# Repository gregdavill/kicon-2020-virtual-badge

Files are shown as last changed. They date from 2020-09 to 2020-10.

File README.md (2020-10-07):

# KiCon 2020 Virtual Badge by Greg Davill

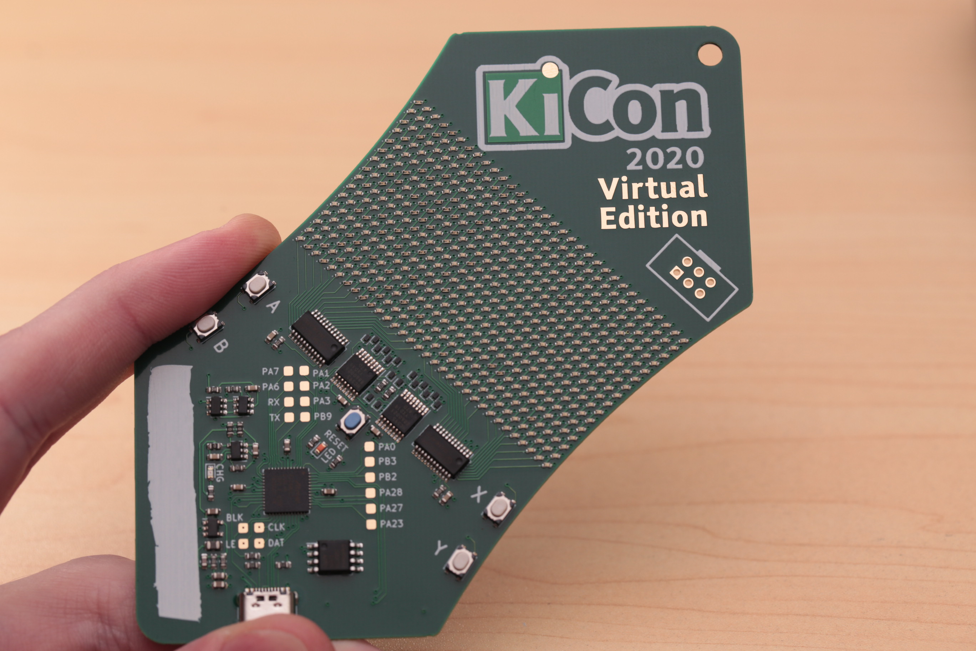
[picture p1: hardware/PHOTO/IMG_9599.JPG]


Based off the design+template by [Thomas Flummer](https://gitlab.com/flummer/kicon-2020-virtual-badge)

I was inspired by the design Thomas made, and wanted to try and extend the badge with more LEDs. I'm using a similar architecture to the LED panels on the d20 and small LED cube I built, except this only has 1 colour of LED in the Matrix.

## Firmware

I've not coded up firmware for a display like this with a microcontroller before, and I've had trouble with the SAMD21's DMA controller and cyclic descriptors in the past. The display will require constant attention from the SAMD as it is a multiplexed display, I'm hoping that implementing a framebuffer + Binary Coded Modulation will be possible.

## Assembly

The LED matrix is 32x16. Or 512 individual LEDs, these are all 0402 in size, so manual assembly may not be for the casual electronics enthusiast.
At any rate I'd recommend using a solderpaste stencil and reflow oven.

## Making your own

If you want to make your own, I have included the gerbers, in case you don't want to install the nightly version.
The board is 4 layers mostly to assist in routing of the matrix. The cost difference between 2L and 4L at JLC is only $5 on their barebones service.

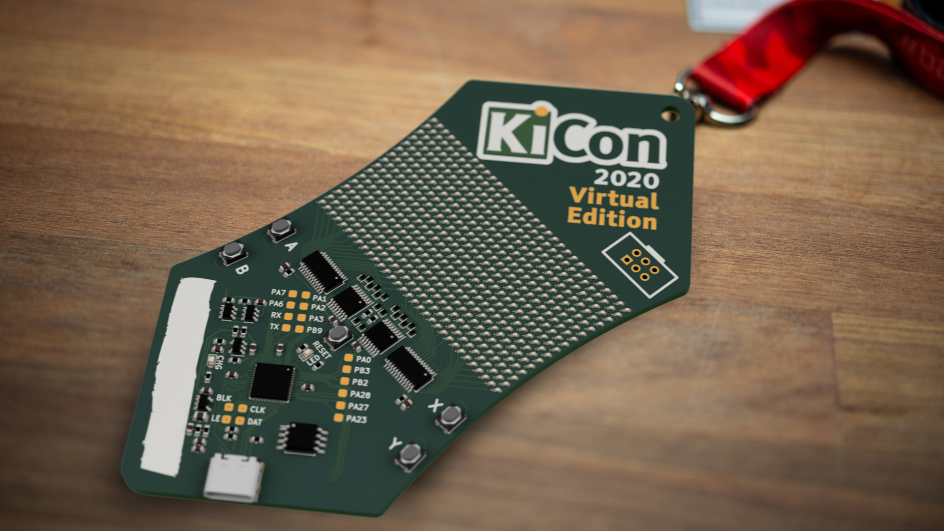
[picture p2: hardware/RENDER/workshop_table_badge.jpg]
Render


## Please share

If you decide to make this badge or a variant of it, please share images so we can all see it and get inspired. If sharing on social media, please use the #badgelife tag and please let [me](https://twitter.com/gregdavill) and [thomas](https://thomasflummer.com/) know, I would love to see what you have made!

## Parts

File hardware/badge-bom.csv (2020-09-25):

Reference | Quantity | Value | Footprint | Datasheet | Mfg | PN | VALUE
C10 | 1 | 10pF | Capacitor_SMD:C_0603_1608Metric | ~ | Samsung Electro-Mechanics | CL10C100JB81PNC
C12 | 1 | 4.7uF | Capacitor_SMD:C_0603_1608Metric | ~ | Samsung Electro-Mechanics | CL10A475KO8NNNC
C5 | 1 | 1uF | Capacitor_SMD:C_0603_1608Metric | ~ | Samsung Electro-Mechanics | CL10B105KO8NNNC
C6 C1 C2 C3 C4 C8 C11 | 7 | 100nF | Capacitor_SMD:C_0603_1608Metric | ~ | Samsung Electro-Mechanics | CL10B104KB8NNNC
C7 C9 C13 C14 | 4 | 10uF | Capacitor_SMD:C_0603_1608Metric | ~ | Samsung Electro-Mechanics | CL10A106MO8NQNC
D1 D2 D3 D4 D5 D6 D7 D8 D9 D10 D11 D12 D13 D14 D15 D16 D17 D18 D19 D20 D21 D22 D23 D24 D25 D26 D27 D28 D29 D30 D31 D32 D33 D34 D35 D36 D37 D38 D39 D40 D41 D42 D43 D44 D45 D46 D47 D48 D49 D50 D51 D52 D53 D54 D55 D56 D57 D58 D59 D60 D61 D62 D63 D64 D65 D66 D67 D68 D69 D70 D71 D72 D73 D74 D75 D76 D77 D78 D79 D80 D81 D82 D83 D84 D85 D86 D87 D88 D89 D90 D91 D92 D93 D94 D95 D96 D97 D98 D99 D100 D101 D102 D103 D104 D105 D106 D107 D108 D109 D110 D111 D112 D113 D114 D115 D116 D117 D118 D119 D120 D121 D122 D123 D124 D125 D126 D127 D128 D129 D130 D131 D132 D133 D134 D135 D136 D137 D138 D139 D140 D141 D142 D143 D144 D145 D146 D147 D148 D149 D150 D151 D152 D153 D154 D155 D156 D157 D158 D159 D160 D161 D162 D163 D164 D165 D166 D167 D168 D169 D170 D171 D172 D173 D174 D175 D176 D177 D178 D179 D180 D181 D182 D183 D184 D185 D186 D187 D188 D189 D190 D191 D192 D193 D194 D195 D196 D197 D198 D199 D200 D201 D202 D203 D204 D205 D206 D207 D208 D209 D210 D211 D212 D213 D214 D215 D216 D217 D218 D219 D220 D221 D222 D223 D224 D225 D226 D227 D228 D229 D230 D231 D232 D233 D234 D235 D236 D237 D238 D239 D240 D241 D242 D243 D244 D245 D246 D247 D248 D249 D250 D251 D252 D253 D254 D255 D256 D257 D258 D259 D260 D261 D262 D263 D264 D265 D266 D267 D268 D269 D270 D271 D272 D273 D274 D275 D276 D277 D278 D279 D280 D281 D282 D283 D284 D285 D286 D287 D288 D289 D290 D291 D292 D293 D294 D295 D296 D297 D298 D299 D300 D301 D302 D303 D304 D305 D306 D307 D308 D309 D310 D311 D312 D313 D314 D315 D316 D317 D318 D319 D320 D321 D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 | 512 | LED | LED_SMD:LED_0402_1005Metric | ~ | Foshan NationStar Optoelectronics | NCD0402O1
D513 | 1 | LED | LED_SMD:LED_0603_1608Metric | ~ | Foshan NationStar Optoelectronics | NCD0603C1
D514 | 1 | CHRG | LED_SMD:LED_0603_1608Metric | ~ | Foshan NationStar Optoelectronics | NCD0603Y1
IC1 | 1 | SAMD21G18A | Package_DFN_QFN:QFN-48-1EP_7x7mm_P0.5mm_EP5.3x5.3mm |  | Microchip Tech | ATSAMD21G16L-MNT | SAMD21G18A-MU
J1 | 1 | USB_C | Connectors:USB_C_Receptacle_U262-161N-4BVC11 | https://www.usb.org/sites/default/files/documents/usb_type-c.zip | XKB Connectivity | U262-161N-4BVC11
J2 | 1 | DEBUG | Connector_PinHeader_2.54mm:PinHeader_1x06_P2.54mm_Vertical | ~
J3 | 1 | LiPo 1S | Connectors:PH2.0-SMD-Horizontal | ~ | JST Sales America | S2B-PH-SM4-TB(LF)(SN)
L1 | 1 | 2.2uH | Inductor_SMD:L_0805_2012Metric | ~ | Sunltech Tech | SLM20122R2MIT
Q1 Q2 Q3 Q4 Q5 Q6 Q7 Q8 Q9 Q10 Q11 Q12 Q13 Q14 Q15 Q16 | 16 | 3412 | Package_TO_SOT_SMD:SOT-883 | ~ | LRC | LP0404N3T5G
R1 R2 R16 | 3 | 2k | Resistor_SMD:R_0603_1608Metric | ~ | UNI-ROYAL(Uniroyal Elec) | 0603WAF2001T5E
R10 | 1 | 100 | Resistor_SMD:R_0603_1608Metric | ~ | UNI-ROYAL(Uniroyal Elec) | 0603WAF1000T5E
R12 R13 R14 | 3 | 1 | Resistor_SMD:R_0603_1608Metric | ~ | UNI-ROYAL(Uniroyal Elec) | 0603WAF0000T5E
R17 | 1 | 360k | Resistor_SMD:R_0603_1608Metric | ~ | UNI-ROYAL(Uniroyal Elec) | 0603WAF3603T5E
R18 | 1 | 82k | Resistor_SMD:R_0603_1608Metric | ~ | UNI-ROYAL(Uniroyal Elec) | 0603WAF8202T5E
R3 R4 | 2 | 5.1k | Resistor_SMD:R_0603_1608Metric | ~ | UNI-ROYAL(Uniroyal Elec) | 0603WAF5101T5E
R5 | 1 | 10k | Resistor_SMD:R_0603_1608Metric | ~ | UNI-ROYAL(Uniroyal Elec) | 0603WAF1002T5E
R6 R11 R15 | 3 | 1k | Resistor_SMD:R_0603_1608Metric | ~ | UNI-ROYAL(Uniroyal Elec) | 0603WAF1001T5E
R7 R8 R9 | 3 | 4.7k | Resistor_SMD:R_0603_1608Metric | ~ | UNI-ROYAL(Uniroyal Elec) | 0603WAF4701T5E
SW1 | 1 | A | Button_Switch_SMD:SW_SPST_PTS810 | ~ | C&K | PTS810SJK250SMTRLFS
SW2 | 1 | B | Button_Switch_SMD:SW_SPST_PTS810 | ~ | C&K | PTS810SJK250SMTRLFS
SW3 | 1 | X | Button_Switch_SMD:SW_SPST_PTS810 | ~ | C&K | PTS810SJK250SMTRLFS
SW4 | 1 | Y | Button_Switch_SMD:SW_SPST_PTS810 | ~ | C&K | PTS810SJK250SMTRLFS
SW5 | 1 | RESET | Button_Switch_SMD:SW_SPST_PTS810 | ~ | C&K | PTS810SJK250SMTRLFS
TP1 | 1 | RX | Connectors:TestPoint_Large | ~
TP10 | 1 | PA28 | Connectors:TestPoint_Large | ~
TP11 | 1 | PA27 | Connectors:TestPoint_Large | ~
TP12 | 1 | PA6 | Connectors:TestPoint_Large | ~
TP13 | 1 | PB23 | Connectors:TestPoint_Large | ~
TP14 | 1 | PA7 | Connectors:TestPoint_Large | ~
TP15 | 1 | PA0 | Connectors:TestPoint_Large | ~
TP16 | 1 | CLK | Connectors:TestPoint_Large | ~
TP17 | 1 | LE | Connectors:TestPoint_Large | ~
TP18 | 1 | BLK | Connectors:TestPoint_Large | ~
TP2 | 1 | TX | Connectors:TestPoint_Large | ~
TP3 | 1 | DAT | Connectors:TestPoint_Large | ~
TP4 | 1 | PB3 | Connectors:TestPoint_Large | ~
TP5 | 1 | PA1 | Connectors:TestPoint_Large | ~
TP6 | 1 | PB2 | Connectors:TestPoint_Large | ~
TP7 | 1 | PA2 | Connectors:TestPoint_Large | ~
TP8 | 1 | PA3 | Connectors:TestPoint_Large | ~
TP9 | 1 | PB9 | Connectors:TestPoint_Large | ~
U1 U2 | 2 | 74HC595 | Package_SO:TSSOP-16_4.4x5mm_P0.65mm | http://www.ti.com/lit/ds/symlink/sn74hc595.pdf | Nexperia | 74HC595PW\,118
U3 U4 | 2 | TLC59025 | Package_SO:SSOP-24_3.9x8.7mm_P0.635mm |  | Texas Instruments | TLC59282DBQR
U5 | 1 | GD25Q32C | Package_SO:SOIC-8_5.23x5.23mm_P1.27mm |  | GigaDevice Semicon Beijing | GD25Q32CSIGR
U6 | 1 | DW01 | Package_TO_SOT_SMD:SOT-23-6 |  | Guangdong Hottech | DW01
U7 | 1 | TLV62569DBV | Package_TO_SOT_SMD:SOT-23-5 | http://www.ti.com/lit/ds/symlink/tlv62569.pdf | Texas Instruments | TLV62569DBVR
U8 | 1 | PM8205A | Package_TO_SOT_SMD:SOT-23-6 |  | PN SILICON | PM8205A
U9 | 1 | HX4054A | Package_TO_SOT_SMD:SOT-23-5 |  | HX(hengjiaxing) | HX4054A
X1 | 1 | #badgelife | badgelife_sao_v169bis:Badgelife-SAOv169-BADGE-2x3

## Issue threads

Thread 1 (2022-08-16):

Pin Allocation for the clock and data lines to the are not optimal

TomKeddie, 2022-08-16:
It's been a while since i worked with this design but I wanted to note here for future reference that white wires are needed to get the sercom/pin allocation correct and use DMA for the led array.

I'll update this issue with the white wires I added but these pin allocations don't allow use of the internal sercom serialiser and thus DMA.

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

gregdavill, 2022-08-17:
Yes, I've actually got a hardware bodge on the one I built to swap these pins to the correct ones.

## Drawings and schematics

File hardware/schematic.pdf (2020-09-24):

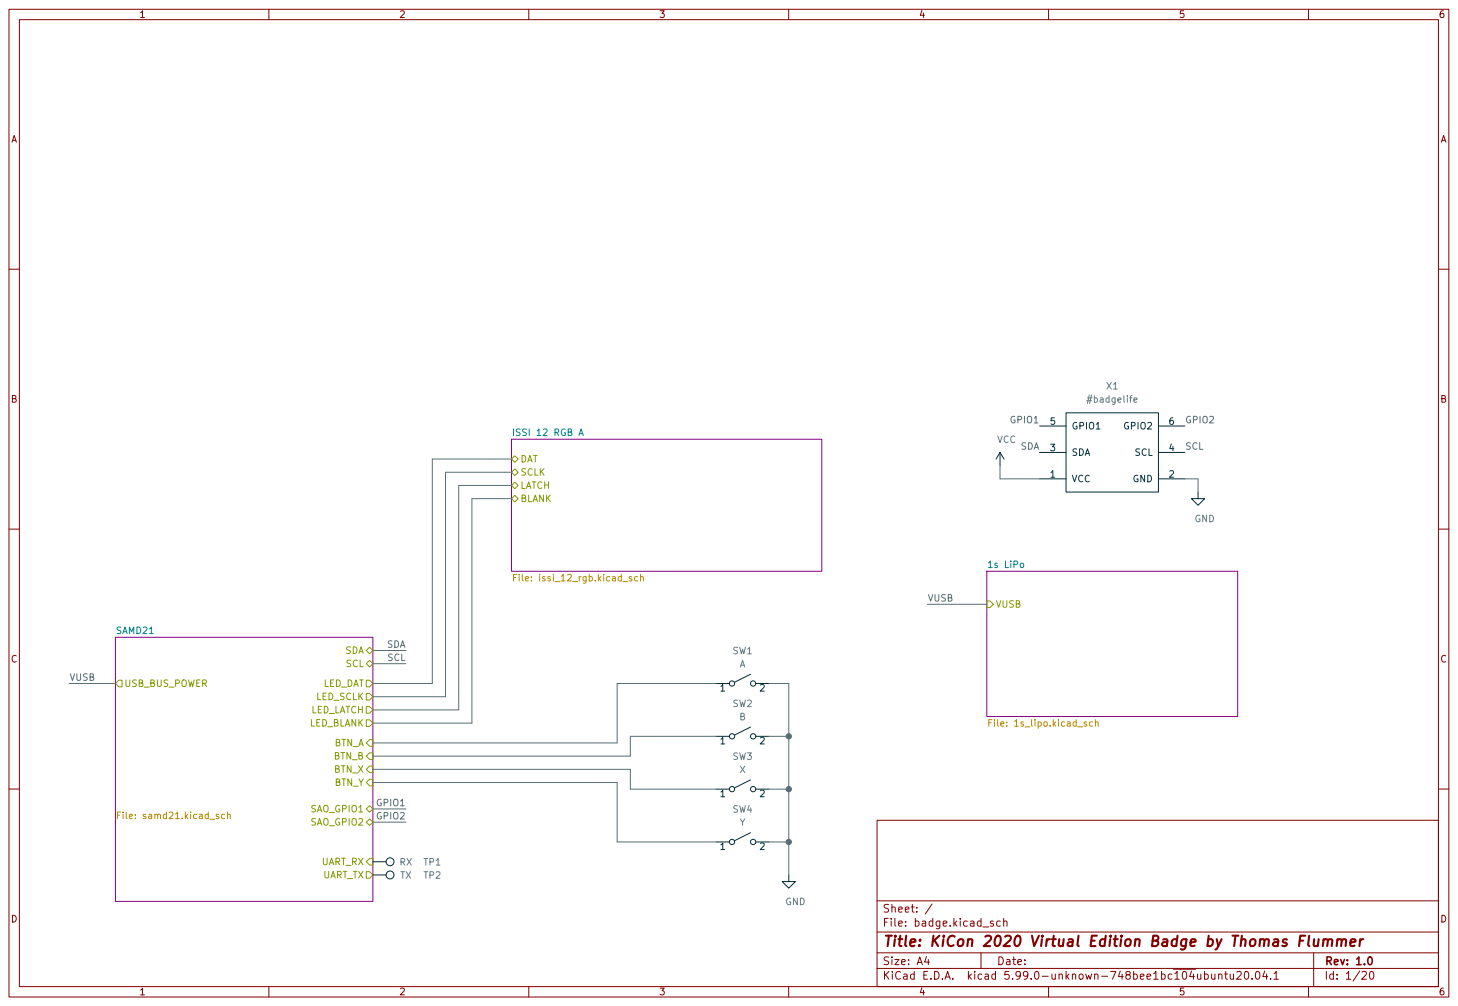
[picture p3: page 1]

Id: 1/20 Title: KiCon 2020 Virtual Edition Badge by Thomas Flummer

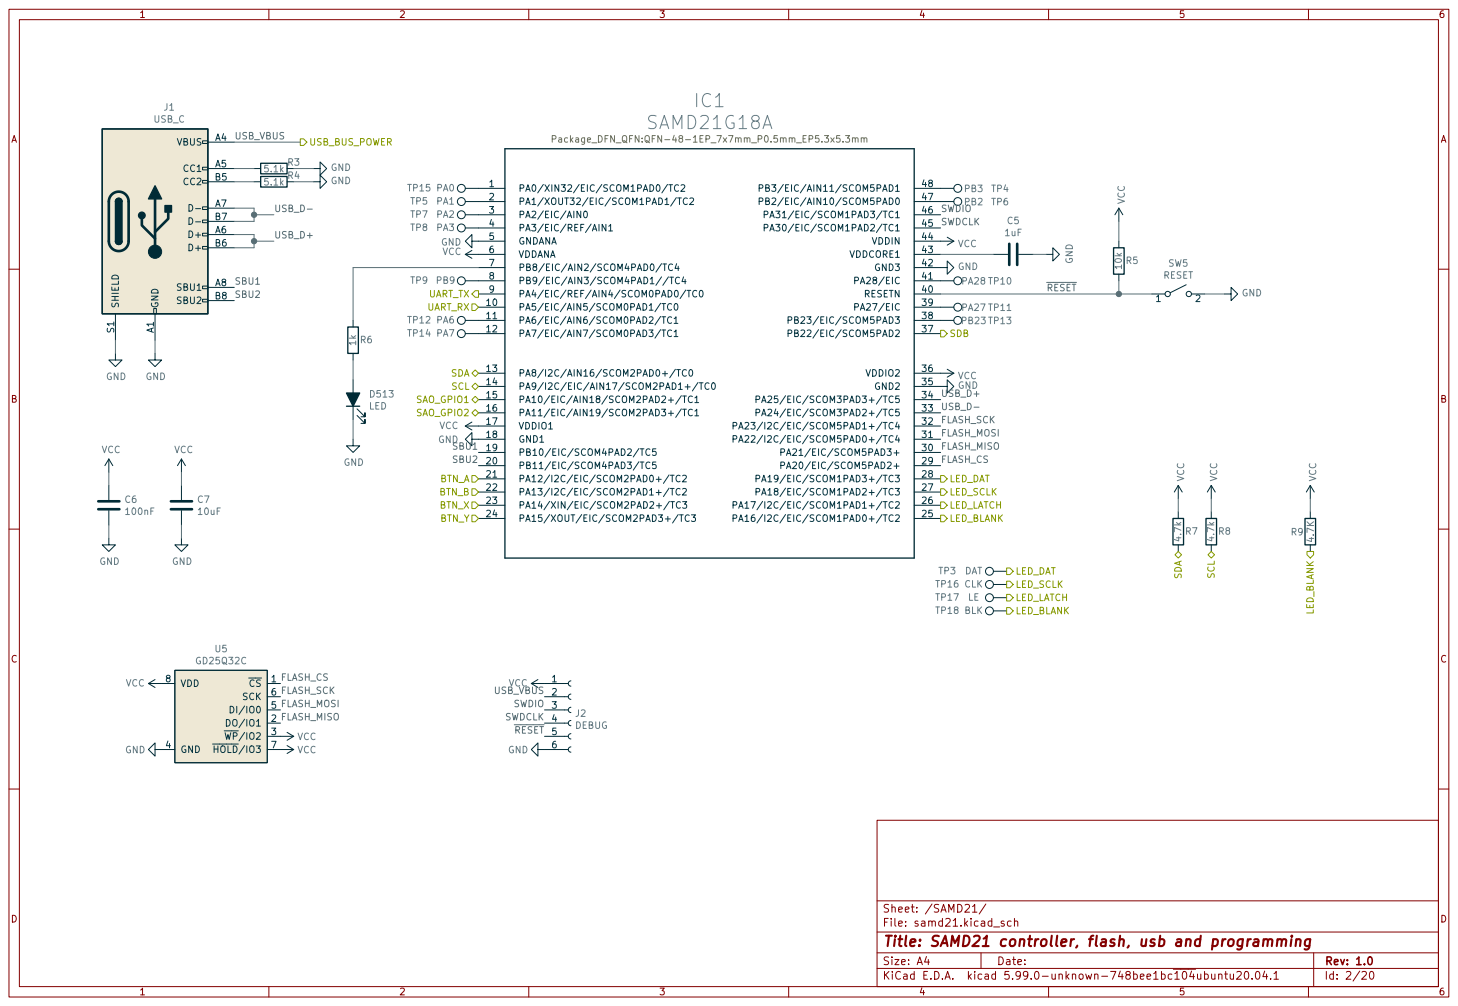
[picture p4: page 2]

Id: 2/20 Title: SAMD21 controller, flash, usb and programming

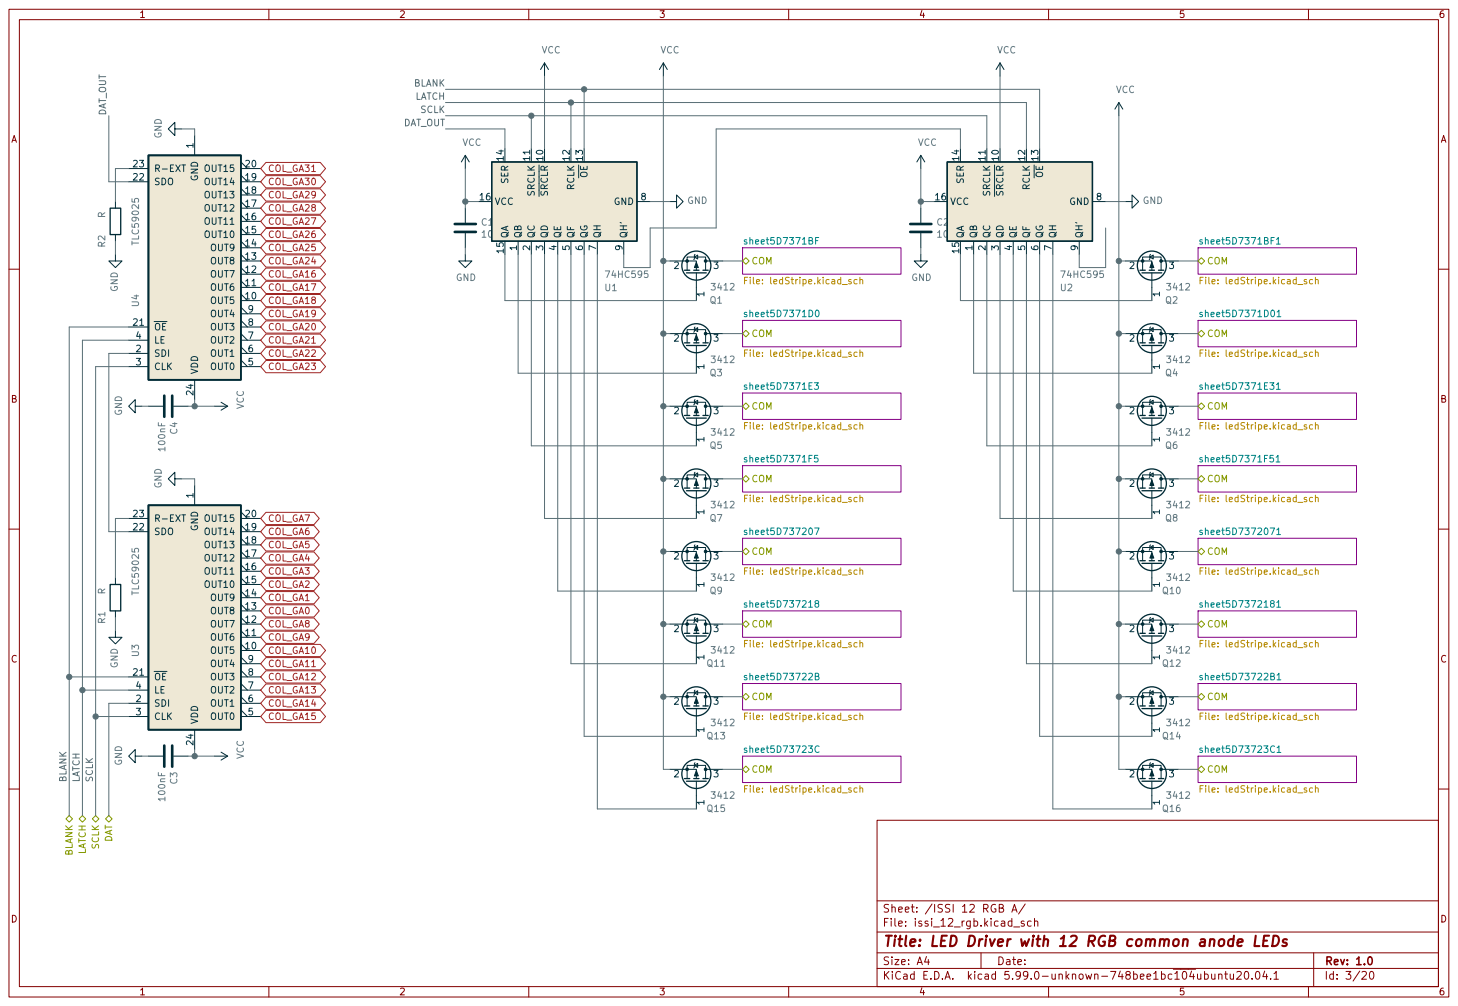
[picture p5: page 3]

File: issi_12_rgb.kicad_sch Sheet: /ISSI 12 RGB A/
Id: 3/20 Title: LED Driver with 12 RGB common anode LEDs

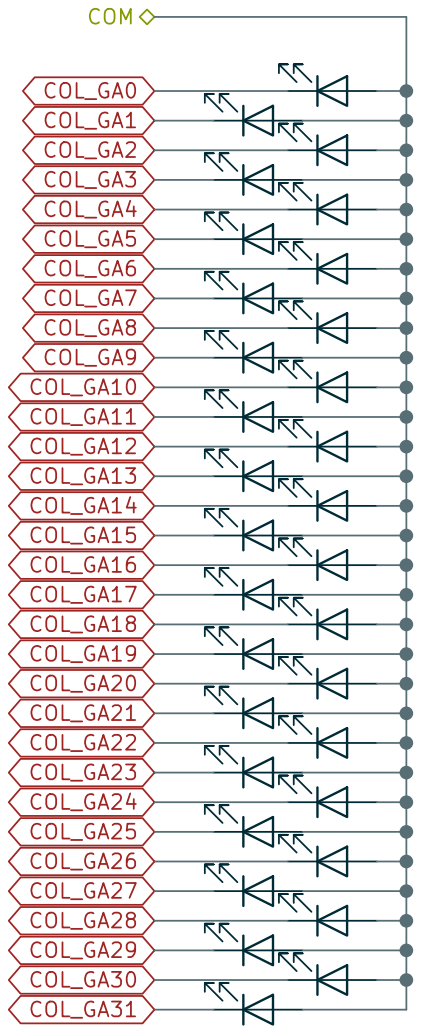
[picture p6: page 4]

File: ledStripe.kicad_sch Sheet: /ISSI 12 RGB A/sheet5D7371BF/

File: ledStripe.kicad_sch Sheet: /ISSI 12 RGB A/sheet5D7371D0/

File: ledStripe.kicad_sch Sheet: /ISSI 12 RGB A/sheet5D7371E3/

File: ledStripe.kicad_sch Sheet: /ISSI 12 RGB A/sheet5D7371F5/

File: ledStripe.kicad_sch Sheet: /ISSI 12 RGB A/sheet5D737207/

File: ledStripe.kicad_sch Sheet: /ISSI 12 RGB A/sheet5D737218/

File: ledStripe.kicad_sch Sheet: /ISSI 12 RGB A/sheet5D73722B/

File: ledStripe.kicad_sch Sheet: /ISSI 12 RGB A/sheet5D73723C/

File: ledStripe.kicad_sch Sheet: /ISSI 12 RGB A/sheet5D7371BF1/

File: ledStripe.kicad_sch Sheet: /ISSI 12 RGB A/sheet5D7371D01/

File: ledStripe.kicad_sch Sheet: /ISSI 12 RGB A/sheet5D7371E31/

File: ledStripe.kicad_sch Sheet: /ISSI 12 RGB A/sheet5D7371F51/

File: ledStripe.kicad_sch Sheet: /ISSI 12 RGB A/sheet5D7372071/

File: ledStripe.kicad_sch Sheet: /ISSI 12 RGB A/sheet5D7372181/

File: ledStripe.kicad_sch Sheet: /ISSI 12 RGB A/sheet5D73722B1/

File: ledStripe.kicad_sch Sheet: /ISSI 12 RGB A/sheet5D73723C1/

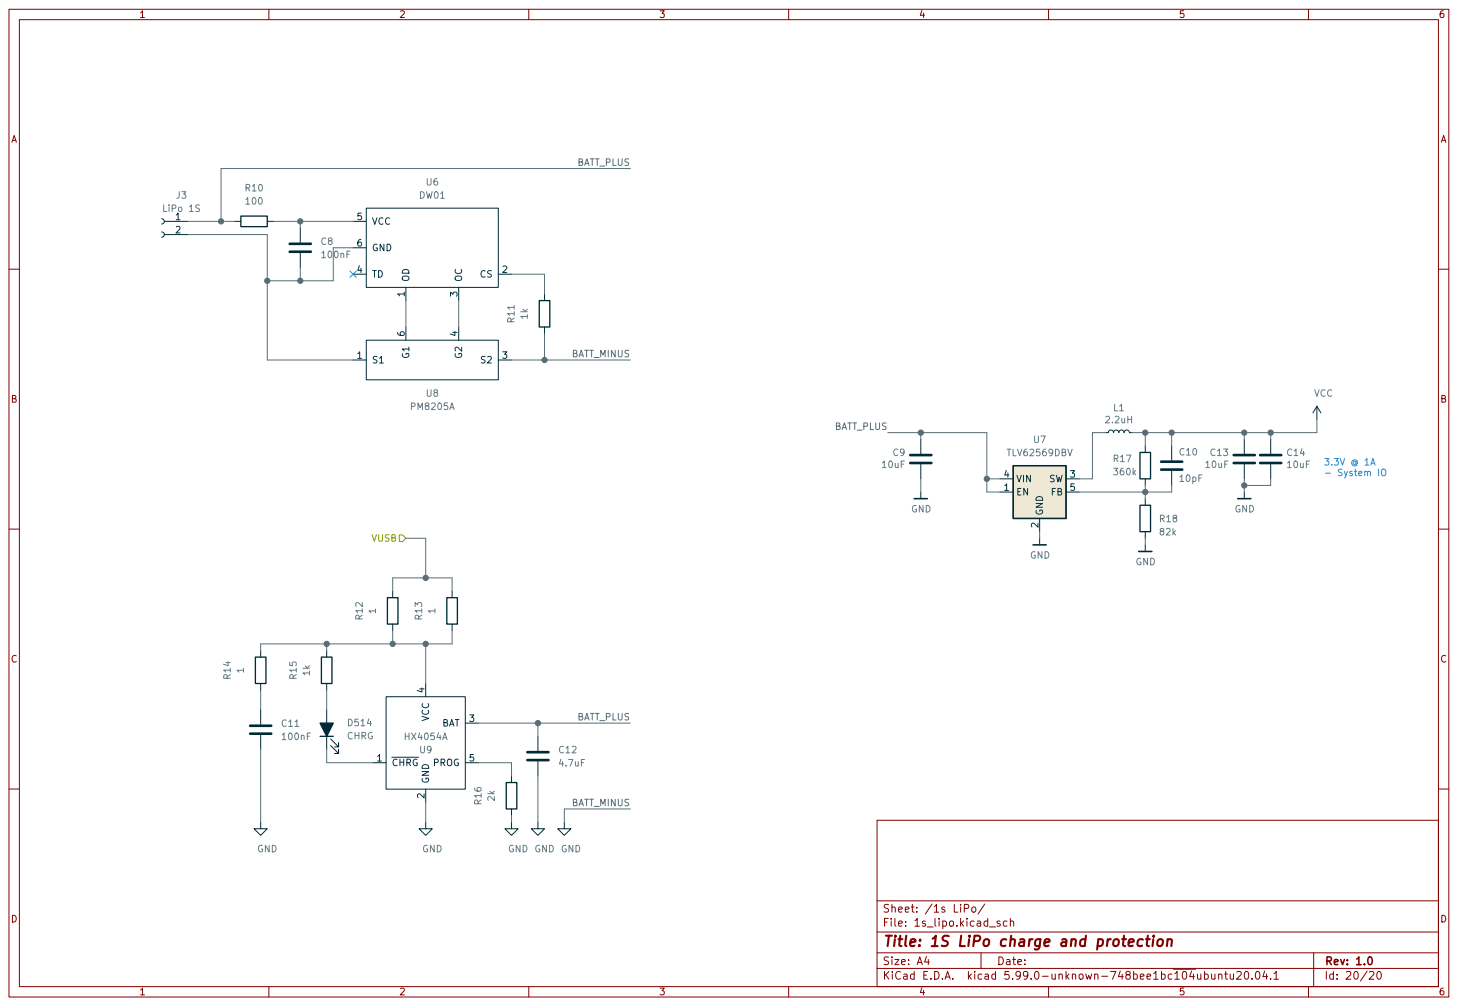
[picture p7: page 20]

3 CS 2 TD 4 VCC 5 GND 6 U6 DW01 C8

Id: 20/20 Title: 1S LiPo charge and protection

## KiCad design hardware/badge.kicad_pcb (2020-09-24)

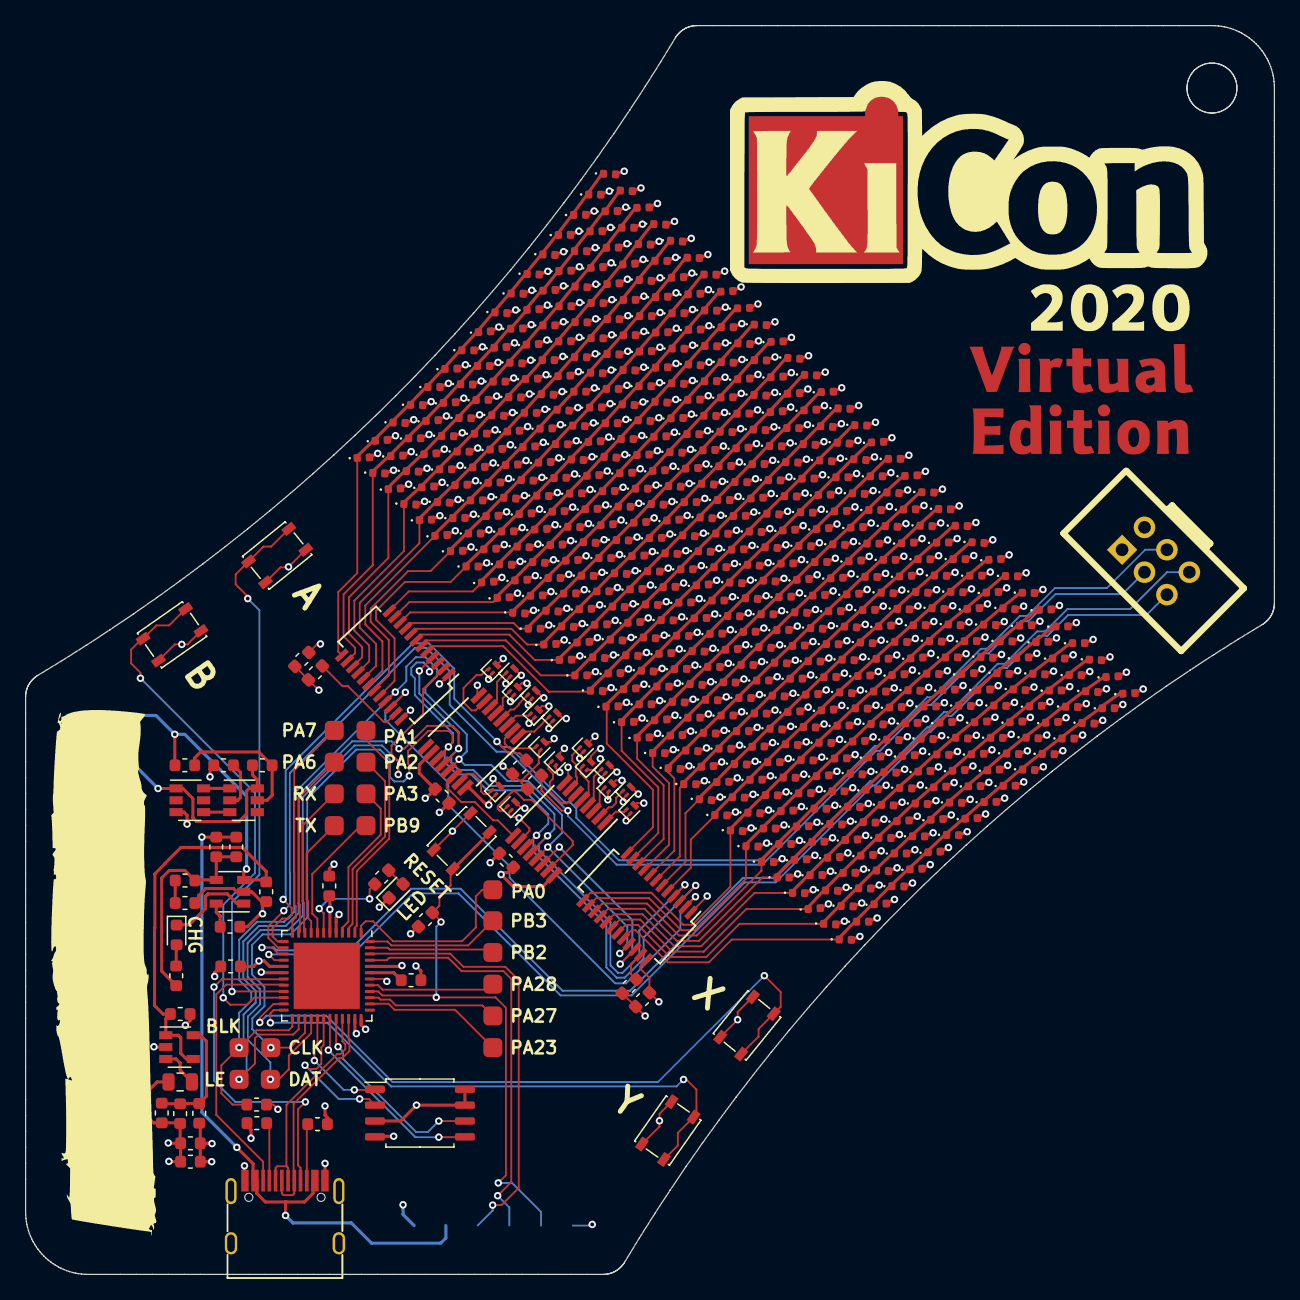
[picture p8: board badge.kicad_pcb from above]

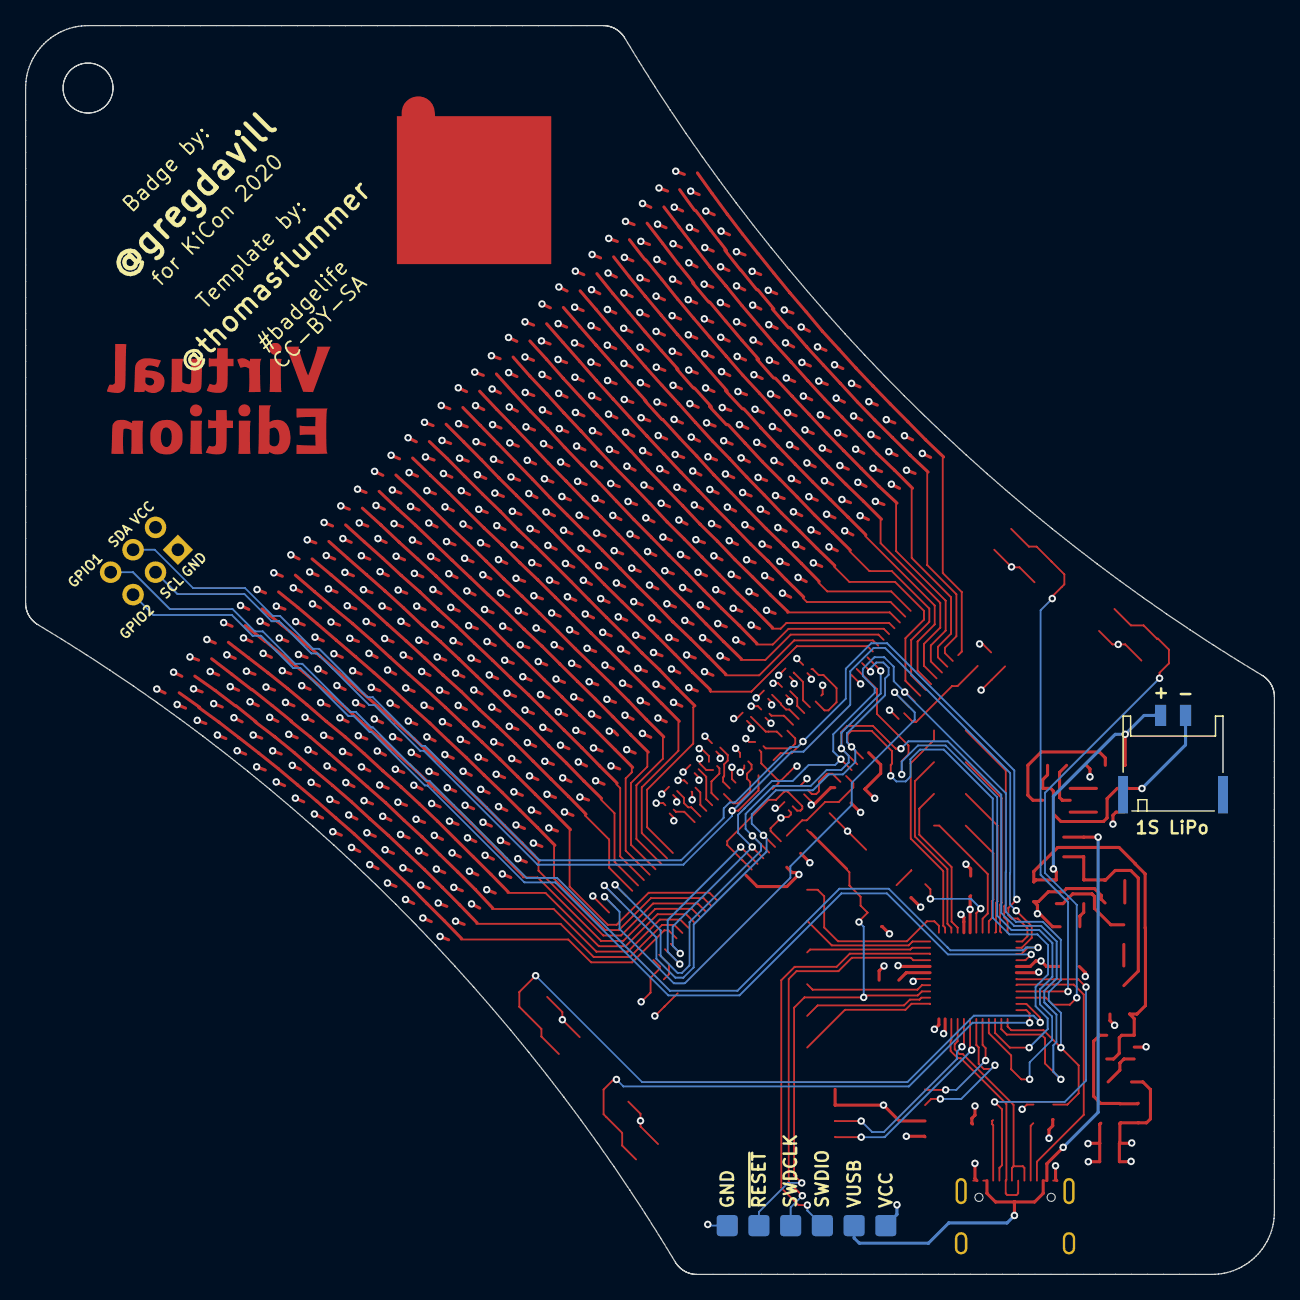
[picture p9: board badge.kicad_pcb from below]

Board: 4 copper layers, 100.0 x 100.0 mm, 600 parts (2 on the bottom side), 127 nets.

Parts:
C1, C2, C3, C4, C6, C8, C11: 100nF; C_0603_1608Metric
C5: 1uF; C_0603_1608Metric
C7, C9, C13, C14: 10uF; C_0603_1608Metric
C10: 10pF; C_0603_1608Metric
C12: 4.7uF; C_0603_1608Metric
D1, D2, D3, D4, D5, D6, D7, D8, D9, D10, D11, D12, D13, D14, D15, D16, D17, D18, D19, D20, D21, D22, D23, D24, D25, D26, D27, D28, D29, D30, D31, D32, D33, D34, D35, D36, D37, D38, D39, D40, D41, D42, D43, D44, D45, D46, D47, D48, D49, D50, D51, D52, D53, D54, D55, D56, D57, D58, D59, D60, D61, D62, D63, D64, D65, D66, D67, D68, D69, D70, D71, D72, D73, D74, D75, D76, D77, D78, D79, D80, D81, D82, D83, D84, D85, D86, D87, D88, D89, D90, D91, D92, D93, D94, D95, D96, D97, D98, D99, D100, D101, D102, D103, D104, D105, D106, D107, D108, D109, D110, D111, D112, D113, D114, D115, D116, D117, D118, D119, D120, D121, D122, D123, D124, D125, D126, D127, D128, D129, D130, D131, D132, D133, D134, D135, D136, D137, D138, D139, D140, D141, D142, D143, D144, D145, D146, D147, D148, D149, D150, D151, D152, D153, D154, D155, D156, D157, D158, D159, D160, D161, D162, D163, D164, D165, D166, D167, D168, D169, D170, D171, D172, D173, D174, D175, D176, D177, D178, D179, D180, D181, D182, D183, D184, D185, D186, D187, D188, D189, D190, D191, D192, D193, D194, D195, D196, D197, D198, D199, D200, D201, D202, D203, D204, D205, D206, D207, D208, D209, D210, D211, D212, D213, D214, D215, D216, D217, D218, D219, D220, D221, D222, D223, D224, D225, D226, D227, D228, D229, D230, D231, D232, D233, D234, D235, D236, D237, D238, D239, D240, D241, D242, D243, D244, D245, D246, D247, D248, D249, D250, D251, D252, D253, D254, D255, D256, D257, D258, D259, D260, D261, D262, D263, D264, D265, D266, D267, D268, D269, D270, D271, D272, D273, D274, D275, D276, D277, D278, D279, D280, D281, D282, D283, D284, D285, D286, D287, D288, D289, D290, D291, D292, D293, D294, D295, D296, D297, D298, D299, D300, D301, D302, D303, D304, D305, D306, D307, D308, D309, D310, D311, D312, D313, D314, D315, D316, D317, D318, D319, D320, D321, D322, D323, D324, D325, D326, D327, D328, D329, D330, D331, D332, D333, D334, D335, D336, D337, D338, D339, D340, D341, D342, D343, D344, D345, D346, D347, D348, D349, D350, D351, D352, D353, D354, D355, D356, D357, D358, D359, D360, D361, D362, D363, D364, D365, D366, D367, D368, D369, D370, D371, D372, D373, D374, D375, D376, D377, D378, D379, D380, D381, D382, D383, D384, D385, D386, D387, D388, D389, D390, D391, D392, D393, D394, D395, D396, D397, D398, D399, D400, D401, D402, D403, D404, D405, D406, D407, D408, D409, D410, D411, D412, D413, D414, D415, D416, D417, D418, D419, D420, D421, D422, D423, D424, D425, D426, D427, D428, D429, D430, D431, D432, D433, D434, D435, D436, D437, D438, D439, D440, D441, D442, D443, D444, D445, D446, D447, D448, D449, D450, D451, D452, D453, D454, D455, D456, D457, D458, D459, D460, D461, D462, D463, D464, D465, D466, D467, D468, D469, D470, D471, D472, D473, D474, D475, D476, D477, D478, D479, D480, D481, D482, D483, D484, D485, D486, D487, D488, D489, D490, D491, D492, D493, D494, D495, D496, D497, D498, D499, D500, D501, D502, D503, D504, D505, D506, D507, D508, D509, D510, D511, D512: LED; LED_0402_1005Metric
D513: LED; LED_0603_1608Metric
D514: CHRG; LED_0603_1608Metric
IC1: SAMD21G18A-MU; QFN-48-1EP_7x7mm_P0.5mm_EP5.3x5.3mm
J1: USB_C; USB_C_Receptacle_U262-161N-4BVC11
J2: DEBUG; PinHeader_1x06_P2.54mm_Vertical
J3: LiPo 1S; PH2.0-SMD-Horizontal
L1: 2.2uH; L_0805_2012Metric
Q1, Q2, Q3, Q4, Q5, Q6, Q7, Q8, Q9, Q10, Q11, Q12, Q13, Q14, Q15, Q16: 3412; SOT-883
R1, R2: R; R_0603_1608Metric
R3, R4: 5.1k; R_0603_1608Metric
R5: 10k; R_0603_1608Metric
R6, R11, R15: 1k; R_0603_1608Metric
R7, R8: 4.7k; R_0603_1608Metric
R9: 4.7K; R_0603_1608Metric
R10: 100; R_0603_1608Metric
R12, R13, R14: 1; R_0603_1608Metric
R16: 2k; R_0603_1608Metric
R17: 360k; R_0603_1608Metric
R18: 82k; R_0603_1608Metric
SW1: A; SW_SPST_PTS810
SW2: B; SW_SPST_PTS810
SW3: X; SW_SPST_PTS810
SW4: Y; SW_SPST_PTS810
SW5: RESET; SW_SPST_PTS810
TP1: RX; TestPoint_Large
TP2: TX; TestPoint_Large
TP3: DAT; TestPoint_Large
TP4: PB3; TestPoint_Large
TP5: PA1; TestPoint_Large
TP6: PB2; TestPoint_Large
TP7: PA2; TestPoint_Large
TP8: PA3; TestPoint_Large
TP9: PB9; TestPoint_Large
TP10: PA28; TestPoint_Large
TP11: PA27; TestPoint_Large
TP12: PA6; TestPoint_Large
TP13: PB23; TestPoint_Large
TP14: PA7; TestPoint_Large
TP15: PA0; TestPoint_Large
TP16: CLK; TestPoint_Large
TP17: LE; TestPoint_Large
TP18: BLK; TestPoint_Large
U1, U2: 74HC595; TSSOP-16_4.4x5mm_P0.65mm
U3, U4: TLC59025; SSOP-24_3.9x8.7mm_P0.635mm
U5: GD25Q32C; SOIC-8_5.23x5.23mm_P1.27mm
U6: DW01; SOT-23-6
U7: TLV62569DBV; SOT-23-5
U8: PM8205A; SOT-23-6
U9: HX4054A; SOT-23-5
X1: #badgelife; Badgelife-SAOv169-BADGE-2x3

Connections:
/1s LiPo/BATT_PLUS: C9.2, C12.1, J3.1, R10.1, U7.1 (EN), U7.4 (VIN), U9.3 (BAT)
/BTN_A: IC1.21 (PA12/I2C/EIC/SCOM2PAD0+/TC2), SW1.1 (A)
/BTN_B: IC1.22 (PA13/I2C/EIC/SCOM2PAD1+/TC2), SW2.1 (A)
/BTN_X: IC1.23 (PA14/XIN/EIC/SCOM2PAD2+/TC3), SW3.1 (A)
/BTN_Y: IC1.24 (PA15/XOUT/EIC/SCOM2PAD3+/TC3), SW4.1 (A)
/GPIO1: IC1.15 (PA10/EIC/AIN18/SCOM2PAD2+/TC1), X1.5 (GPIO1)
/GPIO2: IC1.16 (PA11/EIC/AIN19/SCOM2PAD3+/TC1), X1.6 (GPIO2)
/ISSI 12 RGB A/COM: D321.2 (A), D322.2 (A), D323.2 (A), D324.2 (A), D325.2 (A), D326.2 (A), D327.2 (A), D328.2 (A), D329.2 (A), D330.2 (A), D331.2 (A), D332.2 (A), D333.2 (A), D334.2 (A), D335.2 (A), D336.2 (A), D337.2 (A), D338.2 (A), D339.2 (A), D340.2 (A), D341.2 (A), D342.2 (A), D343.2 (A), D344.2 (A), D345.2 (A), D346.2 (A), D347.2 (A), D348.2 (A), D349.2 (A), D350.2 (A), D351.2 (A), D352.2 (A), Q6.3 (D)
/ISSI 12 RGB A/COM_1: D225.2 (A), D226.2 (A), D227.2 (A), D228.2 (A), D229.2 (A), D230.2 (A), D231.2 (A), D232.2 (A), D233.2 (A), D234.2 (A), D235.2 (A), D236.2 (A), D237.2 (A), D238.2 (A), D239.2 (A), D240.2 (A), D241.2 (A), D242.2 (A), D243.2 (A), D244.2 (A), D245.2 (A), D246.2 (A), D247.2 (A), D248.2 (A), D249.2 (A), D250.2 (A), D251.2 (A), D252.2 (A), D253.2 (A), D254.2 (A), D255.2 (A), D256.2 (A), Q15.3 (D)
/ISSI 12 RGB A/COM_2: D97.2 (A), D98.2 (A), D99.2 (A), D100.2 (A), D101.2 (A), D102.2 (A), D103.2 (A), D104.2 (A), D105.2 (A), D106.2 (A), D107.2 (A), D108.2 (A), D109.2 (A), D110.2 (A), D111.2 (A), D112.2 (A), D113.2 (A), D114.2 (A), D115.2 (A), D116.2 (A), D117.2 (A), D118.2 (A), D119.2 (A), D120.2 (A), D121.2 (A), D122.2 (A), D123.2 (A), D124.2 (A), D125.2 (A), D126.2 (A), D127.2 (A), D128.2 (A), Q7.3 (D)
/ISSI 12 RGB A/COM_3: D129.2 (A), D130.2 (A), D131.2 (A), D132.2 (A), D133.2 (A), D134.2 (A), D135.2 (A), D136.2 (A), D137.2 (A), D138.2 (A), D139.2 (A), D140.2 (A), D141.2 (A), D142.2 (A), D143.2 (A), D144.2 (A), D145.2 (A), D146.2 (A), D147.2 (A), D148.2 (A), D149.2 (A), D150.2 (A), D151.2 (A), D152.2 (A), D153.2 (A), D154.2 (A), D155.2 (A), D156.2 (A), D157.2 (A), D158.2 (A), D159.2 (A), D160.2 (A), Q9.3 (D)
/ISSI 12 RGB A/COM_4: D65.2 (A), D66.2 (A), D67.2 (A), D68.2 (A), D69.2 (A), D70.2 (A), D71.2 (A), D72.2 (A), D73.2 (A), D74.2 (A), D75.2 (A), D76.2 (A), D77.2 (A), D78.2 (A), D79.2 (A), D80.2 (A), D81.2 (A), D82.2 (A), D83.2 (A), D84.2 (A), D85.2 (A), D86.2 (A), D87.2 (A), D88.2 (A), D89.2 (A), D90.2 (A), D91.2 (A), D92.2 (A), D93.2 (A), D94.2 (A), D95.2 (A), D96.2 (A), Q5.3 (D)
/ISSI 12 RGB A/COM_5: D33.2 (A), D34.2 (A), D35.2 (A), D36.2 (A), D37.2 (A), D38.2 (A), D39.2 (A), D40.2 (A), D41.2 (A), D42.2 (A), D43.2 (A), D44.2 (A), D45.2 (A), D46.2 (A), D47.2 (A), D48.2 (A), D49.2 (A), D50.2 (A), D51.2 (A), D52.2 (A), D53.2 (A), D54.2 (A), D55.2 (A), D56.2 (A), D57.2 (A), D58.2 (A), D59.2 (A), D60.2 (A), D61.2 (A), D62.2 (A), D63.2 (A), D64.2 (A), Q3.3 (D)
/ISSI 12 RGB A/COM_6: D1.2 (A), D2.2 (A), D3.2 (A), D4.2 (A), D5.2 (A), D6.2 (A), D7.2 (A), D8.2 (A), D9.2 (A), D10.2 (A), D11.2 (A), D12.2 (A), D13.2 (A), D14.2 (A), D15.2 (A), D16.2 (A), D17.2 (A), D18.2 (A), D19.2 (A), D20.2 (A), D21.2 (A), D22.2 (A), D23.2 (A), D24.2 (A), D25.2 (A), D26.2 (A), D27.2 (A), D28.2 (A), D29.2 (A), D30.2 (A), D31.2 (A), D32.2 (A), Q1.3 (D)
/ISSI 12 RGB A/COM_7: D257.2 (A), D258.2 (A), D259.2 (A), D260.2 (A), D261.2 (A), D262.2 (A), D263.2 (A), D264.2 (A), D265.2 (A), D266.2 (A), D267.2 (A), D268.2 (A), D269.2 (A), D270.2 (A), D271.2 (A), D272.2 (A), D273.2 (A), D274.2 (A), D275.2 (A), D276.2 (A), D277.2 (A), D278.2 (A), D279.2 (A), D280.2 (A), D281.2 (A), D282.2 (A), D283.2 (A), D284.2 (A), D285.2 (A), D286.2 (A), D287.2 (A), D288.2 (A), Q2.3 (D)
/ISSI 12 RGB A/COM_8: D161.2 (A), D162.2 (A), D163.2 (A), D164.2 (A), D165.2 (A), D166.2 (A), D167.2 (A), D168.2 (A), D169.2 (A), D170.2 (A), D171.2 (A), D172.2 (A), D173.2 (A), D174.2 (A), D175.2 (A), D176.2 (A), D177.2 (A), D178.2 (A), D179.2 (A), D180.2 (A), D181.2 (A), D182.2 (A), D183.2 (A), D184.2 (A), D185.2 (A), D186.2 (A), D187.2 (A), D188.2 (A), D189.2 (A), D190.2 (A), D191.2 (A), D192.2 (A), Q11.3 (D)
/ISSI 12 RGB A/COM_9: D417.2 (A), D418.2 (A), D419.2 (A), D420.2 (A), D421.2 (A), D422.2 (A), D423.2 (A), D424.2 (A), D425.2 (A), D426.2 (A), D427.2 (A), D428.2 (A), D429.2 (A), D430.2 (A), D431.2 (A), D432.2 (A), D433.2 (A), D434.2 (A), D435.2 (A), D436.2 (A), D437.2 (A), D438.2 (A), D439.2 (A), D440.2 (A), D441.2 (A), D442.2 (A), D443.2 (A), D444.2 (A), D445.2 (A), D446.2 (A), D447.2 (A), D448.2 (A), Q12.3 (D)
/ISSI 12 RGB A/COM_10: D449.2 (A), D450.2 (A), D451.2 (A), D452.2 (A), D453.2 (A), D454.2 (A), D455.2 (A), D456.2 (A), D457.2 (A), D458.2 (A), D459.2 (A), D460.2 (A), D461.2 (A), D462.2 (A), D463.2 (A), D464.2 (A), D465.2 (A), D466.2 (A), D467.2 (A), D468.2 (A), D469.2 (A), D470.2 (A), D471.2 (A), D472.2 (A), D473.2 (A), D474.2 (A), D475.2 (A), D476.2 (A), D477.2 (A), D478.2 (A), D479.2 (A), D480.2 (A), Q14.3 (D)
/ISSI 12 RGB A/COM_11: D481.2 (A), D482.2 (A), D483.2 (A), D484.2 (A), D485.2 (A), D486.2 (A), D487.2 (A), D488.2 (A), D489.2 (A), D490.2 (A), D491.2 (A), D492.2 (A), D493.2 (A), D494.2 (A), D495.2 (A), D496.2 (A), D497.2 (A), D498.2 (A), D499.2 (A), D500.2 (A), D501.2 (A), D502.2 (A), D503.2 (A), D504.2 (A), D505.2 (A), D506.2 (A), D507.2 (A), D508.2 (A), D509.2 (A), D510.2 (A), D511.2 (A), D512.2 (A), Q16.3 (D)
/ISSI 12 RGB A/COM_12: D353.2 (A), D354.2 (A), D355.2 (A), D356.2 (A), D357.2 (A), D358.2 (A), D359.2 (A), D360.2 (A), D361.2 (A), D362.2 (A), D363.2 (A), D364.2 (A), D365.2 (A), D366.2 (A), D367.2 (A), D368.2 (A), D369.2 (A), D370.2 (A), D371.2 (A), D372.2 (A), D373.2 (A), D374.2 (A), D375.2 (A), D376.2 (A), D377.2 (A), D378.2 (A), D379.2 (A), D380.2 (A), D381.2 (A), D382.2 (A), D383.2 (A), D384.2 (A), Q8.3 (D)
/ISSI 12 RGB A/COM_13: D385.2 (A), D386.2 (A), D387.2 (A), D388.2 (A), D389.2 (A), D390.2 (A), D391.2 (A), D392.2 (A), D393.2 (A), D394.2 (A), D395.2 (A), D396.2 (A), D397.2 (A), D398.2 (A), D399.2 (A), D400.2 (A), D401.2 (A), D402.2 (A), D403.2 (A), D404.2 (A), D405.2 (A), D406.2 (A), D407.2 (A), D408.2 (A), D409.2 (A), D410.2 (A), D411.2 (A), D412.2 (A), D413.2 (A), D414.2 (A), D415.2 (A), D416.2 (A), Q10.3 (D)
/ISSI 12 RGB A/COM_14: D193.2 (A), D194.2 (A), D195.2 (A), D196.2 (A), D197.2 (A), D198.2 (A), D199.2 (A), D200.2 (A), D201.2 (A), D202.2 (A), D203.2 (A), D204.2 (A), D205.2 (A), D206.2 (A), D207.2 (A), D208.2 (A), D209.2 (A), D210.2 (A), D211.2 (A), D212.2 (A), D213.2 (A), D214.2 (A), D215.2 (A), D216.2 (A), D217.2 (A), D218.2 (A), D219.2 (A), D220.2 (A), D221.2 (A), D222.2 (A), D223.2 (A), D224.2 (A), Q13.3 (D)
/ISSI 12 RGB A/COM_15: D289.2 (A), D290.2 (A), D291.2 (A), D292.2 (A), D293.2 (A), D294.2 (A), D295.2 (A), D296.2 (A), D297.2 (A), D298.2 (A), D299.2 (A), D300.2 (A), D301.2 (A), D302.2 (A), D303.2 (A), D304.2 (A), D305.2 (A), D306.2 (A), D307.2 (A), D308.2 (A), D309.2 (A), D310.2 (A), D311.2 (A), D312.2 (A), D313.2 (A), D314.2 (A), D315.2 (A), D316.2 (A), D317.2 (A), D318.2 (A), D319.2 (A), D320.2 (A), Q4.3 (D)
/ISSI 12 RGB A/DAT_OUT: U1.14 (SER), U4.22 (SDO)
/LED_BLANK: IC1.25 (PA16/I2C/EIC/SCOM1PAD0+/TC2), R9.2, TP18.1, U1.13 (~OE), U2.13 (~OE), U3.21 (~OE), U4.21 (~OE)
/LED_DAT: IC1.28 (PA19/EIC/SCOM1PAD3+/TC3), TP3.1, U3.2 (SDI)
/LED_LATCH: IC1.26 (PA17/I2C/EIC/SCOM1PAD1+/TC2), TP17.1, U1.12 (RCLK), U2.12 (RCLK), U3.4 (LE), U4.4 (LE)
/LED_SCLK: IC1.27 (PA18/EIC/SCOM1PAD2+/TC3), TP16.1, U1.11 (SRCLK), U2.11 (SRCLK), U3.3 (CLK), U4.3 (CLK)
/SAMD21/FLASH_CS: IC1.29 (PA20/EIC/SCOM5PAD2+), U5.1 (~CS~)
/SAMD21/FLASH_MISO: IC1.30 (PA21/EIC/SCOM5PAD3+), U5.2 (DO/IO1)
/SAMD21/FLASH_MOSI: IC1.31 (PA22/I2C/EIC/SCOM5PAD0+/TC4), U5.5 (DI/IO0)
/SAMD21/FLASH_SCK: IC1.32 (PA23/I2C/EIC/SCOM5PAD1+/TC4), U5.6 (SCK)
/SAMD21/SBU1: IC1.19 (PB10/EIC/SCOM4PAD2/TC5), J1.A8 (SBU1)
/SAMD21/SBU2: IC1.20 (PB11/EIC/SCOM4PAD3/TC5), J1.B8 (SBU2)
/SAMD21/SWDCLK: IC1.45 (PA30/EIC/SCOM1PAD2/TC1), J2.4
/SAMD21/SWDIO: IC1.46 (PA31/EIC/SCOM1PAD3/TC1), J2.3
/SAMD21/USB_D+: IC1.34 (PA25/EIC/SCOM3PAD3+/TC5), J1.A6 (D+), J1.B6 (D+)
/SAMD21/USB_D-: IC1.33 (PA24/EIC/SCOM3PAD2+/TC5), J1.A7 (D-), J1.B7 (D-)
/SAMD21/~RESET: IC1.40 (RESETN), J2.5, R5.1, SW5.1 (A)
/SCL: IC1.14 (PA9/I2C/EIC/AIN17/SCOM2PAD1+/TC0), R8.1, X1.4 (SCL)
/SDA: IC1.13 (PA8/I2C/AIN16/SCOM2PAD0+/TC0), R7.1, X1.3 (SDA)
/UART_RX: IC1.10 (PA5/EIC/AIN5/SCOM0PAD1/TC0), TP1.1
/UART_TX: IC1.9 (PA4/EIC/REF/AIN4/SCOM0PAD0/TC0), TP2.1
/VUSB: J1.A4 (VBUS), J1.A9 (VBUS), J1.B4 (VBUS), J1.B9 (VBUS), J2.2, R12.2, R13.2
COL_GA0: D1.1 (K), D33.1 (K), D65.1 (K), D97.1 (K), D129.1 (K), D161.1 (K), D193.1 (K), D225.1 (K), D257.1 (K), D289.1 (K), D321.1 (K), D353.1 (K), D385.1 (K), D417.1 (K), D449.1 (K), D481.1 (K), U3.13 (OUT8)
COL_GA1: D2.1 (K), D34.1 (K), D66.1 (K), D98.1 (K), D130.1 (K), D162.1 (K), D194.1 (K), D226.1 (K), D258.1 (K), D290.1 (K), D322.1 (K), D354.1 (K), D386.1 (K), D418.1 (K), D450.1 (K), D482.1 (K), U3.14 (OUT9)
COL_GA2: D3.1 (K), D35.1 (K), D67.1 (K), D99.1 (K), D131.1 (K), D163.1 (K), D195.1 (K), D227.1 (K), D259.1 (K), D291.1 (K), D323.1 (K), D355.1 (K), D387.1 (K), D419.1 (K), D451.1 (K), D483.1 (K), U3.15 (OUT10)
COL_GA3: D4.1 (K), D36.1 (K), D68.1 (K), D100.1 (K), D132.1 (K), D164.1 (K), D196.1 (K), D228.1 (K), D260.1 (K), D292.1 (K), D324.1 (K), D356.1 (K), D388.1 (K), D420.1 (K), D452.1 (K), D484.1 (K), U3.16 (OUT11)
COL_GA4: D5.1 (K), D37.1 (K), D69.1 (K), D101.1 (K), D133.1 (K), D165.1 (K), D197.1 (K), D229.1 (K), D261.1 (K), D293.1 (K), D325.1 (K), D357.1 (K), D389.1 (K), D421.1 (K), D453.1 (K), D485.1 (K), U3.17 (OUT12)
COL_GA5: D6.1 (K), D38.1 (K), D70.1 (K), D102.1 (K), D134.1 (K), D166.1 (K), D198.1 (K), D230.1 (K), D262.1 (K), D294.1 (K), D326.1 (K), D358.1 (K), D390.1 (K), D422.1 (K), D454.1 (K), D486.1 (K), U3.18 (OUT13)
COL_GA6: D7.1 (K), D39.1 (K), D71.1 (K), D103.1 (K), D135.1 (K), D167.1 (K), D199.1 (K), D231.1 (K), D263.1 (K), D295.1 (K), D327.1 (K), D359.1 (K), D391.1 (K), D423.1 (K), D455.1 (K), D487.1 (K), U3.19 (OUT14)
COL_GA7: D8.1 (K), D40.1 (K), D72.1 (K), D104.1 (K), D136.1 (K), D168.1 (K), D200.1 (K), D232.1 (K), D264.1 (K), D296.1 (K), D328.1 (K), D360.1 (K), D392.1 (K), D424.1 (K), D456.1 (K), D488.1 (K), U3.20 (OUT15)
COL_GA8: D9.1 (K), D41.1 (K), D73.1 (K), D105.1 (K), D137.1 (K), D169.1 (K), D201.1 (K), D233.1 (K), D265.1 (K), D297.1 (K), D329.1 (K), D361.1 (K), D393.1 (K), D425.1 (K), D457.1 (K), D489.1 (K), U3.12 (OUT7)
COL_GA9: D10.1 (K), D42.1 (K), D74.1 (K), D106.1 (K), D138.1 (K), D170.1 (K), D202.1 (K), D234.1 (K), D266.1 (K), D298.1 (K), D330.1 (K), D362.1 (K), D394.1 (K), D426.1 (K), D458.1 (K), D490.1 (K), U3.11 (OUT6)
COL_GA10: D11.1 (K), D43.1 (K), D75.1 (K), D107.1 (K), D139.1 (K), D171.1 (K), D203.1 (K), D235.1 (K), D267.1 (K), D299.1 (K), D331.1 (K), D363.1 (K), D395.1 (K), D427.1 (K), D459.1 (K), D491.1 (K), U3.10 (OUT5)
COL_GA11: D12.1 (K), D44.1 (K), D76.1 (K), D108.1 (K), D140.1 (K), D172.1 (K), D204.1 (K), D236.1 (K), D268.1 (K), D300.1 (K), D332.1 (K), D364.1 (K), D396.1 (K), D428.1 (K), D460.1 (K), D492.1 (K), U3.9 (OUT4)
COL_GA12: D13.1 (K), D45.1 (K), D77.1 (K), D109.1 (K), D141.1 (K), D173.1 (K), D205.1 (K), D237.1 (K), D269.1 (K), D301.1 (K), D333.1 (K), D365.1 (K), D397.1 (K), D429.1 (K), D461.1 (K), D493.1 (K), U3.8 (OUT3)
COL_GA13: D14.1 (K), D46.1 (K), D78.1 (K), D110.1 (K), D142.1 (K), D174.1 (K), D206.1 (K), D238.1 (K), D270.1 (K), D302.1 (K), D334.1 (K), D366.1 (K), D398.1 (K), D430.1 (K), D462.1 (K), D494.1 (K), U3.7 (OUT2)
COL_GA14: D15.1 (K), D47.1 (K), D79.1 (K), D111.1 (K), D143.1 (K), D175.1 (K), D207.1 (K), D239.1 (K), D271.1 (K), D303.1 (K), D335.1 (K), D367.1 (K), D399.1 (K), D431.1 (K), D463.1 (K), D495.1 (K), U3.6 (OUT1)
COL_GA15: D16.1 (K), D48.1 (K), D80.1 (K), D112.1 (K), D144.1 (K), D176.1 (K), D208.1 (K), D240.1 (K), D272.1 (K), D304.1 (K), D336.1 (K), D368.1 (K), D400.1 (K), D432.1 (K), D464.1 (K), D496.1 (K), U3.5 (OUT0)
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

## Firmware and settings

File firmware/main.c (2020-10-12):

#include <samd51.h>


//uint32_t frame_buffer[16];


extern const uint32_t never[];
extern const uint32_t gamma[];


void delay(int n)
{
    int i;

    for (;n >0; n--)
    {
            __asm("nop");
    }
}

void led_toggle() {
    PORT->Group[1].OUTTGL.reg = (1<<8);
    PORT->Group[0].OUTTGL.reg = (1<<17);
    delay(1);
}


void timer_start(int count){
    if(count == 0){
        count = 1;
    }
    /* Load timer */
    TC0->COUNT16.CTRLBSET.reg = TC_CTRLBSET_CMD_STOP;
    TC0->COUNT16.COUNT.reg = count;
    while(TC0->COUNT16.SYNCBUSY.reg & TCC_SYNCBUSY_COUNT);

    /*Start */ 
    EVSYS->SWEVT.reg = EVSYS_SWEVT_CHANNEL0; // Note channel is x-1 (0 is no channel)
   

    
    //TC0->COUNT16.CTRLBSET.reg = TC_CTRLBSET_CMD_RETRIGGER;



    while(!(TC0->COUNT16.INTFLAG.reg & TC_INTFLAG_OVF));
    TC0->COUNT16.INTFLAG.reg = TC_INTFLAG_OVF;
}

void timer_init(){
    MCLK->APBAMASK.bit.TC0_ = 1;
    GCLK->PCHCTRL[TC0_GCLK_ID].reg = GCLK_PCHCTRL_GEN_GCLK0
                                   | GCLK_PCHCTRL_CHEN;

    TC0->COUNT32.CTRLA.reg = TC_CTRLA_SWRST;
    while(TC0->COUNT16.SYNCBUSY.reg & TC_SYNCBUSY_SWRST);

    TC0->COUNT16.EVCTRL.reg = TC_EVCTRL_OVFEO
                            | TC_EVCTRL_TCEI
                            | TC_EVCTRL_EVACT_START;



    TC0->COUNT16.CTRLBSET.reg = TC_CTRLBSET_ONESHOT | TC_CTRLBSET_DIR;
    TC0->COUNT32.CTRLA.reg = TC_CTRLA_ENABLE;
    while(TC0->COUNT16.SYNCBUSY.reg & TC_SYNCBUSY_ENABLE);


    MCLK->APBBMASK.bit.EVSYS_ = 1;
    GCLK->PCHCTRL[EVSYS_GCLK_ID_0].reg = GCLK_PCHCTRL_GEN_GCLK0
                                   | GCLK_PCHCTRL_CHEN;
    GCLK->PCHCTRL[EVSYS_GCLK_ID_1].reg = GCLK_PCHCTRL_GEN_GCLK0
                                   | GCLK_PCHCTRL_CHEN;
    
    /* CLEAR BLANK on EVENT0 */
    EVSYS->Channel[0].CHANNEL.reg = EVSYS_CHANNEL_EVGEN(0) 
                                  | EVSYS_CHANNEL_PATH_ASYNCHRONOUS; // SW triggered
    EVSYS->USER[EVSYS_ID_USER_PORT_EV_0].reg = EVSYS_USER_CHANNEL(0+1); // Note channel is x-1 (0 is no channel)
    EVSYS->USER[EVSYS_ID_USER_TC0_EVU].reg = EVSYS_USER_CHANNEL(0+1); // Note channel is x-1 (0 is no channel)

    /* Set BLANK on EVENT 1*/
    EVSYS->Channel[1].CHANNEL.reg = EVSYS_CHANNEL_EVGEN(EVSYS_ID_GEN_TC0_OVF)
                                  | EVSYS_CHANNEL_PATH_ASYNCHRONOUS;
    EVSYS->USER[EVSYS_ID_USER_PORT_EV_1].reg = EVSYS_USER_CHANNEL(1+1); // Note channel is x-1 (0 is no channel)
   
}

void spi_init(){
    // LED BLANK = PA16
    // LED LATCH = PA18
    // LED SCLK = PA17
    // LED DAT = PA19    

    MCLK->APBAMASK.reg |= MCLK_APBAMASK_SERCOM1;
    GCLK->PCHCTRL[SERCOM1_GCLK_ID_CORE].reg = GCLK_PCHCTRL_GEN_GCLK0
                                            | GCLK_PCHCTRL_CHEN;


    SERCOM1->SPI.CTRLA.reg |= SERCOM_SPI_CTRLA_SWRST;
    while(SERCOM1->SPI.SYNCBUSY.reg & SERCOM_SPI_SYNCBUSY_SWRST);

    SERCOM1->SPI.CTRLA.reg = SERCOM_SPI_CTRLA_DOPO(2)
                           | SERCOM_SPI_CTRLA_MODE(3)
                           | SERCOM_SPI_CTRLA_DORD;
    SERCOM1->SPI.CTRLC.reg = SERCOM_SPI_CTRLC_DATA32B;
    SERCOM1->SPI.BAUD.reg = 0;
    SERCOM1->SPI.CTRLA.reg |= SERCOM_SPI_CTRLA_ENABLE;
    while(SERCOM1->SPI.SYNCBUSY.reg & SERCOM_SPI_SYNCBUSY_ENABLE);
    

    PORT->Group[0].PMUX[17>>1].bit.PMUXO = 2;
    PORT->Group[0].PINCFG[17].bit.PMUXEN = 1;

    PORT->Group[0].PMUX[19>>1].bit.PMUXO = 2;
    PORT->Group[0].PINCFG[19].bit.PMUXEN = 1;
}


int frame = 0;
int main()
{
    PORT->Group[1].DIRSET.reg = (1 << 8);
    
    
    
    PORT->Group[0].DIRSET.reg = (1 << 16) | (1 << 18);
    
    PORT->Group[0].OUTCLR.reg = (1 << 16); // Ignore BLANK


    GCLK->GENCTRL[0].reg = GCLK_GENCTRL_DIV(0) 
                         | GCLK_GENCTRL_GENEN
                         | GCLK_GENCTRL_SRC_DFLL;


    /* PORT EVENT 0, CLEAR 16*/
    PORT->Group[0].EVCTRL.reg = PORT_EVCTRL_PORTEI0
                              | PORT_EVCTRL_EVACT0(PORT_EVCTRL_EVACT0_CLR_Val)
                              | PORT_EVCTRL_PID0(16)
                              | PORT_EVCTRL_PORTEI1
                              | PORT_EVCTRL_EVACT1(PORT_EVCTRL_EVACT0_SET_Val)
                              | PORT_EVCTRL_PID1(16);
                              


    spi_init();

    timer_init();

    int i = 0;

    int col = 0;
    

    int d = 0;
    int c = 0;

    while(1){
        
        for(int k = 0; k < 8; k++){
            bitplane(col, k);
        }
        if(++col >= 16){
            i++;   
            col = 0;


            if(i > 40){
                i = 0;
                frame++;

                if(frame > 499)
                    frame = 0;
            }
        }
    }

}


void bitplane(uint32_t col, uint32_t offset){
    

    uint32_t mask = ~(0x10000 << col);
    while(!SERCOM1->SPI.INTFLAG.bit.DRE){}
    SERCOM1->SPI.DATA.reg = mask;

    while(!SERCOM1->SPI.INTFLAG.bit.DRE){}
    SERCOM1->SPI.DATA.reg = never[col + 16*offset + frame*16*8];

    while(!SERCOM1->SPI.INTFLAG.bit.TXC){}

    PORT->Group[0].OUTCLR.reg = (1 << 18);
    PORT->Group[0].OUTSET.reg = (1 << 18);
    
    //PORT->Group[0].OUTCLR.reg = (1 << 16);
    //timer_start(5<<offset);
    timer_start(gamma[offset]/2);
    //PORT->Group[0].OUTSET.reg = (1 << 16);
}

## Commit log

2020-09-13 Initial commit
    KiCon 2020 Virtual Badge template
    [badge.kicad_pcb, badge.kicad_sch]
2020-09-21 Added schematic, board and gerbers for my fork
    [1s_lipo.kicad_sch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]
2020-09-24 gregdavill: Initial commit of new badge design
    [1s_lipo.kicad_sch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]
2020-09-24 Tidy up design
    [1s_lipo.kicad_sch, issi_12_rgb.kicad_sch]
2020-09-25 add BOM
    [1s_lipo.kicad_sch, badge-bom.csv, badge.kicad_sch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]
2020-10-07 Improve folder structure
    [1s_lipo.kicad_sch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]
2020-10-11 firmware: Add low level SPI code.

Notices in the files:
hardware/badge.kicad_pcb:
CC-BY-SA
